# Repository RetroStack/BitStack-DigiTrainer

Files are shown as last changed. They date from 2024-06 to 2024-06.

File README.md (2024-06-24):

# DigiTrainer

As part of an introduction in digital electronics workshop at VCF SW 2024, I prepared this board. The intent was to reduce lookup time for datasheets and being able to just connect the inputs and outputs of various gates and logic ICs without caring too much about power supplies. In addition, this board features DIP-switches, a toggle and slide switch, hexadecimal switches, LED arrays which do have a built in resistor for current limiting, pull-up and -down resistors, and much more.

In addition to all of that, it includes a section for a Z80 CPU, static memory, and a ROM to be able to learn to program and work with 8-bit CPUs.

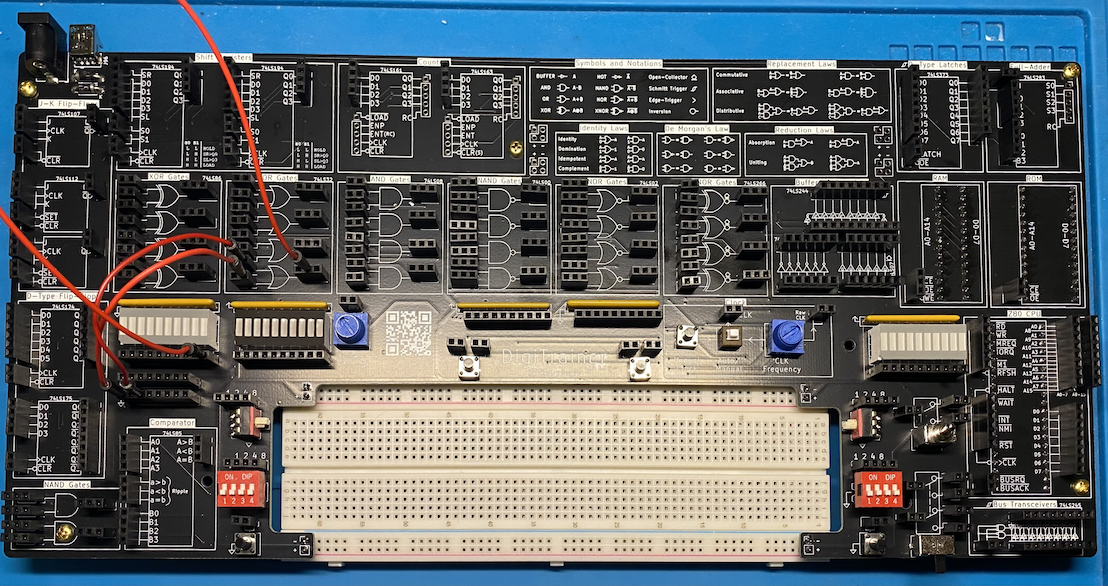
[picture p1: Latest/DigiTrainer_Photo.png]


## Latest Files

In the "Latest" folder, you'll find the most up-to-date design files, including:

- Gerber files suitable for popular online PCB manufacturers like [PCBWay](/Latest/DigiTrainer_Gerber_PCBWay.zip) and [JLCPCB](/Latest/DigiTrainer_Gerber_JLCPCB.zip). Most manufacturers should be fine with either.
- A Bill of Materials (BOM) in both [CSV](/Latest/DigiTrainer_BOM.csv) and [PDF](/Latest/DigiTrainer_BOM.pdf) formats.
- The [full schematics](/Latest/DigiTrainer_Schematics.pdf) of the board.

## Implementation

The board has been implemented using KiCAD 8. The KiCAD project files are included in this repository.

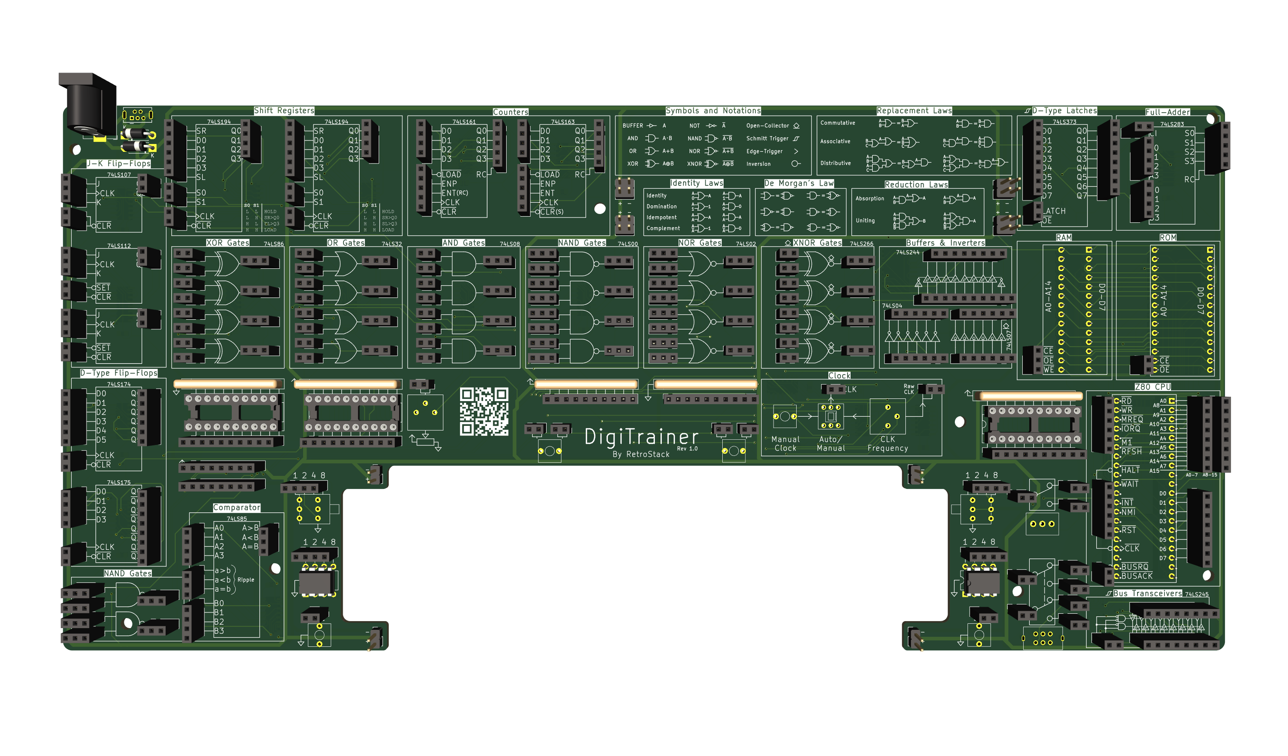
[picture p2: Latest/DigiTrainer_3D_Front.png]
Front

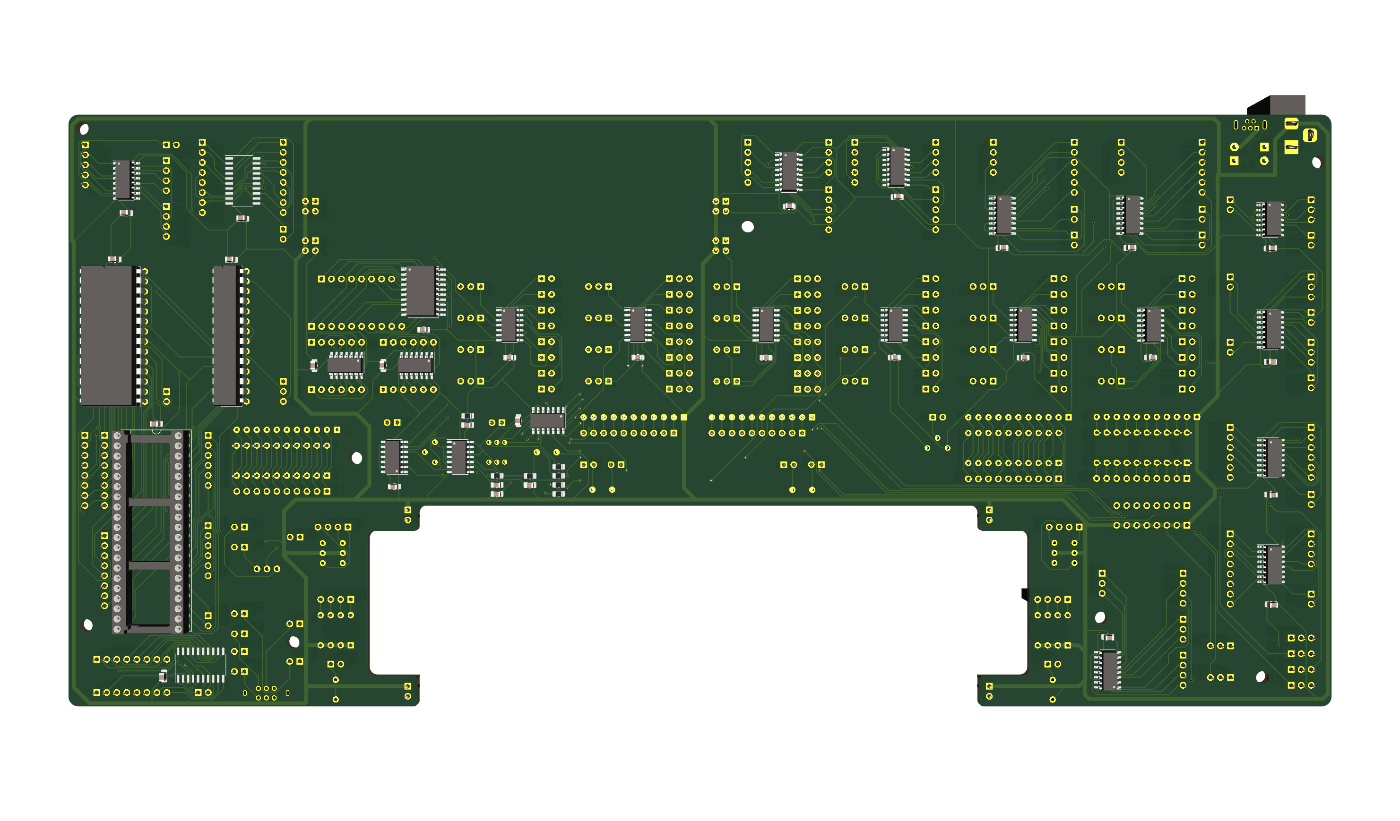
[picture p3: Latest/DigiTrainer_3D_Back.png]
Back


## How to Use

All inputs of various ICs and gates are on the left side of the indicated gate or IC, while outputs are on the right side of the silkscreen indications. Bi-directional pins are horizontal or on the output side (such as at the Z80 CPU for the data bus).

Many components are already connected to +5V or GND and are indicated by an "arrow up" and "triangle down" respectively. Keep in mind that an LED connected to an IC output with +5V acts as an inverted output due to current sinking.

The top right area also provides a legend of common rules/laws and symbols used in digital electronics (and logic as an extension of it).

## Bill of Materials (BOM)

Below is a list of materials needed to assemble the PCB.

| Reference | Qty | Description | Footprint | Datasheet |
| --- | --- | --- | --- | --- |
| C1,C2,C3,C4,C5,C6,C7,C8,C9,C10,C11,C12,C13,C14,C15,C16,C17,C18,C19,C20,C25,C26,C27,C28,C29,C30 | 26  | 0.1uF | Capacitor_SMD:C_0805_2012Metric_Pad1.18x1.45mm_HandSolder  | ~ |
| C21,C24 | 2 | 1uF | Capacitor_SMD:C_0805_2012Metric_Pad1.18x1.45mm_HandSolder  | ~ |
| C22,C23 | 2 | 0.01uF | Capacitor_SMD:C_0805_2012Metric_Pad1.18x1.45mm_HandSolder  | ~ |
| D1,D2 | 2 | D_Schottky | Diode_THT:D_DO-41_SOD81_P7.62mm_Horizontal | ~ |
| DN1,DN2,DN3 | 3 | LED Array | Package_DIP:DIP-20_W7.62mm_Socket | ~ |
| J1,J2,J86,J158,J159,J160 | 6 | Conn_01x10 | Connector_PinSocket_2.54mm:PinSocket_1x10_P2.54mm_Vertical | ~ |
| J3,J16,J17,J18,J19,J20,J21,J22,J23,J24,J25,J26,J27,J28,J29,J30,J31,J54,J55,J56,J57,J58,J59,J60,J61,J62,J63,J64,J65,J66,J67,J68,J69,J89,J99,J100,J102,J109,J110,J111,J112,J113,J114,J122,J123,J125,J126,J133,J137,J138,J142,J144,J145,J146,J147,J148,J149,J150,J151,J152,J153,J154,J155,J156,J157,J163,J168 | 67  | Conn_01x02 | Connector_PinSocket_2.54mm:PinSocket_1x02_P2.54mm_Vertical | ~ |
| J4,J5,J6,J7,J8,J9,J10,J11,J12,J13,J14,J15,J32,J33,J34,J35,J36,J37,J38,J39,J40,J41,J42,J43,J44,J45,J46,J47,J48,J49,J50,J51,J52,J53,J70,J71,J72,J73,J74,J75,J76,J77,J78,J79,J80,J81,J87,J106,J107,J108,J135,J136,J141,J143,J167,J169 | 56  | Conn_01x03 | Connector_PinSocket_2.54mm:PinSocket_1x03_P2.54mm_Vertical | ~ |
| J82,J83,J84,J85,J98,J103,J121,J124,J161,J162 | 10  | Conn_01x06 | Connector_PinSocket_2.54mm:PinSocket_1x06_P2.54mm_Vertical | ~ |
| J88,J90,J91,J101,J104,J105,J164,J165,J166,J173,J174 | 11  | Conn_01x08 | Connector_PinSocket_2.54mm:PinSocket_1x08_P2.54mm_Vertical | ~ |
| J92,J93,J94,J172 | 4 | Conn_02x02_Odd_Even | Connector_PinHeader_2.54mm:PinHeader_2x02_P2.54mm_Vertical | ~ |
| J95 | 1 | Barrel_Jack_Switch  | Connector_BarrelJack:BarrelJack_Horizontal | ~ |
| J96 | 1 | USB_B_Mini | Connector_USB:USB_Mini-B_Tensility_54-00023_Vertical | ~ |
| J97,J115,J117,J127,J128,J129,J130,J131,J132,J139,J140,J170,J171 | 13  | Conn_01x04 | Connector_PinSocket_2.54mm:PinSocket_1x04_P2.54mm_Vertical | ~ |
| J116,J118,J119,J120,J134 | 5 | Conn_01x05 | Connector_PinSocket_2.54mm:PinSocket_1x05_P2.54mm_Vertical | ~ |
| R1,R2,R3 | 3 | 10k | Resistor_SMD:R_0805_2012Metric_Pad1.20x1.40mm_HandSolder | ~ |
| R4,R5,R6,R7 | 4 | 1k | Resistor_SMD:R_0805_2012Metric_Pad1.20x1.40mm_HandSolder | ~ |
| RN1,RN2,RN3,RN4,RN5 | 5 | R_Network10 | Resistor_THT:R_Array_SIP11 | http://www.vishay.com/docs/31509/csc.pdf |
| RV1 | 1 | R_Potentiometer | Potentiometer_THT:Potentiometer_Bourns_3386P_Vertical | ~ |
| RV2 | 1 | 1M | Potentiometer_THT:Potentiometer_Bourns_3386P_Vertical | ~ |
| SW1,SW5,SW6,SW7,SW8 | 5 | SW_Push | RetroStackLibrary:SW_SPST_Push | ~ |
| SW2 | 1 | SW_DPDT_x2 | RetroStackLibrary:SW_DPDT_Push | ~ |
| SW3,SW4 | 2 | SW_DIP_x04 | Package_DIP:DIP-8_W7.62mm | ~ |
| SW9 | 1 | SW_SPDT | RetroStackLibrary:SW_SPDT_Toggle | ~ |
| SW10 | 1 | SW_Push_DPDT | RetroStackLibrary:SW_DPDT_Slide_RightAngle | ~ |
| SW11,SW12 | 2 | Hex Switch | RetroStackLibrary:SW_Hexadecimal_Horizontal | https://www.ckswitches.com/media/1333/cd.pdf |
| U1 | 1 | 74LS07 | Package_SO:SOIC-14_3.9x8.7mm_P1.27mm | www.ti.com/lit/ds/symlink/sn74ls07.pdf |
| U2 | 1 | 74LS04 | Package_SO:SOIC-14_3.9x8.7mm_P1.27mm | http://www.ti.com/lit/gpn/sn74LS04 |
| U3 | 1 | 74LS266 | Package_SO:SOIC-14_3.9x8.7mm_P1.27mm | ~ |
| U4,U5 | 2 | 74LS00 | Package_SO:SOIC-14_3.9x8.7mm_P1.27mm | http://www.ti.com/lit/gpn/sn74ls00 |
| U6 | 1 | 74LS08 | Package_SO:SOIC-14_3.9x8.7mm_P1.27mm | http://www.ti.com/lit/gpn/sn74LS08 |
| U7 | 1 | 74LS86 | Package_SO:SOIC-14_3.9x8.7mm_P1.27mm | 74xx/74ls86.pdf |
| U8 | 1 | 74LS32 | Package_SO:SOIC-14_3.9x8.7mm_P1.27mm | http://www.ti.com/lit/gpn/sn74LS32 |
| U9 | 1 | 74LS02 | Package_SO:SOIC-14_3.9x8.7mm_P1.27mm | http://www.ti.com/lit/gpn/sn74ls02 |
| U10 | 1 | 74LS244 | Package_SO:SOIC-20W_7.5x12.8mm_P1.27mm | http://www.ti.com/lit/ds/symlink/sn74ls244.pdf |
| U11 | 1 | 74LS245 | Package_SO:SO-20_5.3x12.6mm_P1.27mm | http://www.ti.com/lit/gpn/sn74LS245 |
| U12 | 1 | 74LS51 | Package_SO:SOIC-14_3.9x8.7mm_P1.27mm | http://www.ti.com/lit/ds/symlink/sn74ls51.pdf |
| U13 | 1 | 74LS174 | Package_SO:SOIC-16_3.9x9.9mm_P1.27mm | http://www.ti.com/lit/gpn/sn74LS174 |
| U14 | 1 | 74LS175 | Package_SO:SOIC-16_3.9x9.9mm_P1.27mm | http://www.ti.com/lit/gpn/sn74LS175 |
| U15 | 1 | 74LS373 | Package_SO:SO-20_5.3x12.6mm_P1.27mm | http://www.ti.com/lit/gpn/sn74LS373 |
| U16 | 1 | 74LS112 | Package_SO:SOIC-16_3.9x9.9mm_P1.27mm | http://www.ti.com/lit/gpn/sn74LS112 |
| U17 | 1 | 74LS107 | Package_SO:SOIC-14_3.9x8.7mm_P1.27mm | http://www.ti.com/lit/gpn/sn74LS107 |
| U18 | 1 | 74LS161 | Package_SO:SOIC-16_3.9x9.9mm_P1.27mm | http://www.ti.com/lit/gpn/sn74LS161 |
| U19 | 1 | 74LS163 | Package_SO:SOIC-16_3.9x9.9mm_P1.27mm | http://www.ti.com/lit/gpn/sn74LS163 |
| U20,U21 | 2 | 74LS194 | Package_SO:SOIC-16_3.9x9.9mm_P1.27mm | http://www.ti.com/lit/gpn/sn74LS194 |
| U22 | 1 | 74LS283 | Package_SO:SOIC-16_3.9x9.9mm_P1.27mm | http://www.ti.com/lit/gpn/sn74LS283 |
| U23 | 1 | 74LS85 | Package_SO:SOIC-16_3.9x9.9mm_P1.27mm | http://www.ti.com/lit/gpn/sn74LS85 |
| U24 | 1 | NE556 | Package_SO:SOIC-14_3.9x8.7mm_P1.27mm | http://www.ti.com/lit/ds/symlink/ne556.pdf |
| U25 | 1 | Z80CPU | Package_DIP:DIP-40_W15.24mm_Socket | www.zilog.com/manage_directlink.php?filepath=docs/z80/um0080 |
| U26 | 1 | ROM_27256 | Package_DIP:DIP-28_W15.24mm | ~ |
| U27 | 1 | CY7C199 | Package_DIP:DIP-28_W7.62mm | ~ |

## RetroStack Libraries

To work with this KiCAD project, you'll need the RetroStack libraries for KiCAD. Please [follow this link](https://www.github.com/RetroStack/KiCAD-Libraries) to access and install these libraries.

## Support this Project

RetroStack is passionate about exploring and preserving the legacy of older computer systems. BitStack is a sub-project of RetroStack, focusing on education in digital electronics. My work involves creating detailed documentation and videos to share the knowledge. I am also dedicated to reviving these classic systems by reimplementing them and offering replacement parts at no cost. If you're keen on supporting this unique project, I invite you to visit my [Patreon page](https://www.patreon.com/RetroStack). Your support would be immensely valuable and greatly appreciated!

## License

This project is licensed under the MIT License - see the [LICENSE](LICENSE) file for details.

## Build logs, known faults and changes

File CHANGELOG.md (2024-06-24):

# DigiTrainer - Changelog

## 24th June 2024 - Rev 1.0

Completed test. Fully functional.

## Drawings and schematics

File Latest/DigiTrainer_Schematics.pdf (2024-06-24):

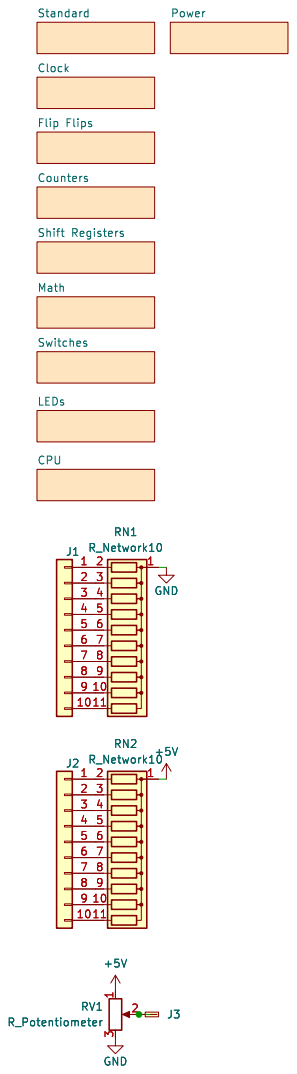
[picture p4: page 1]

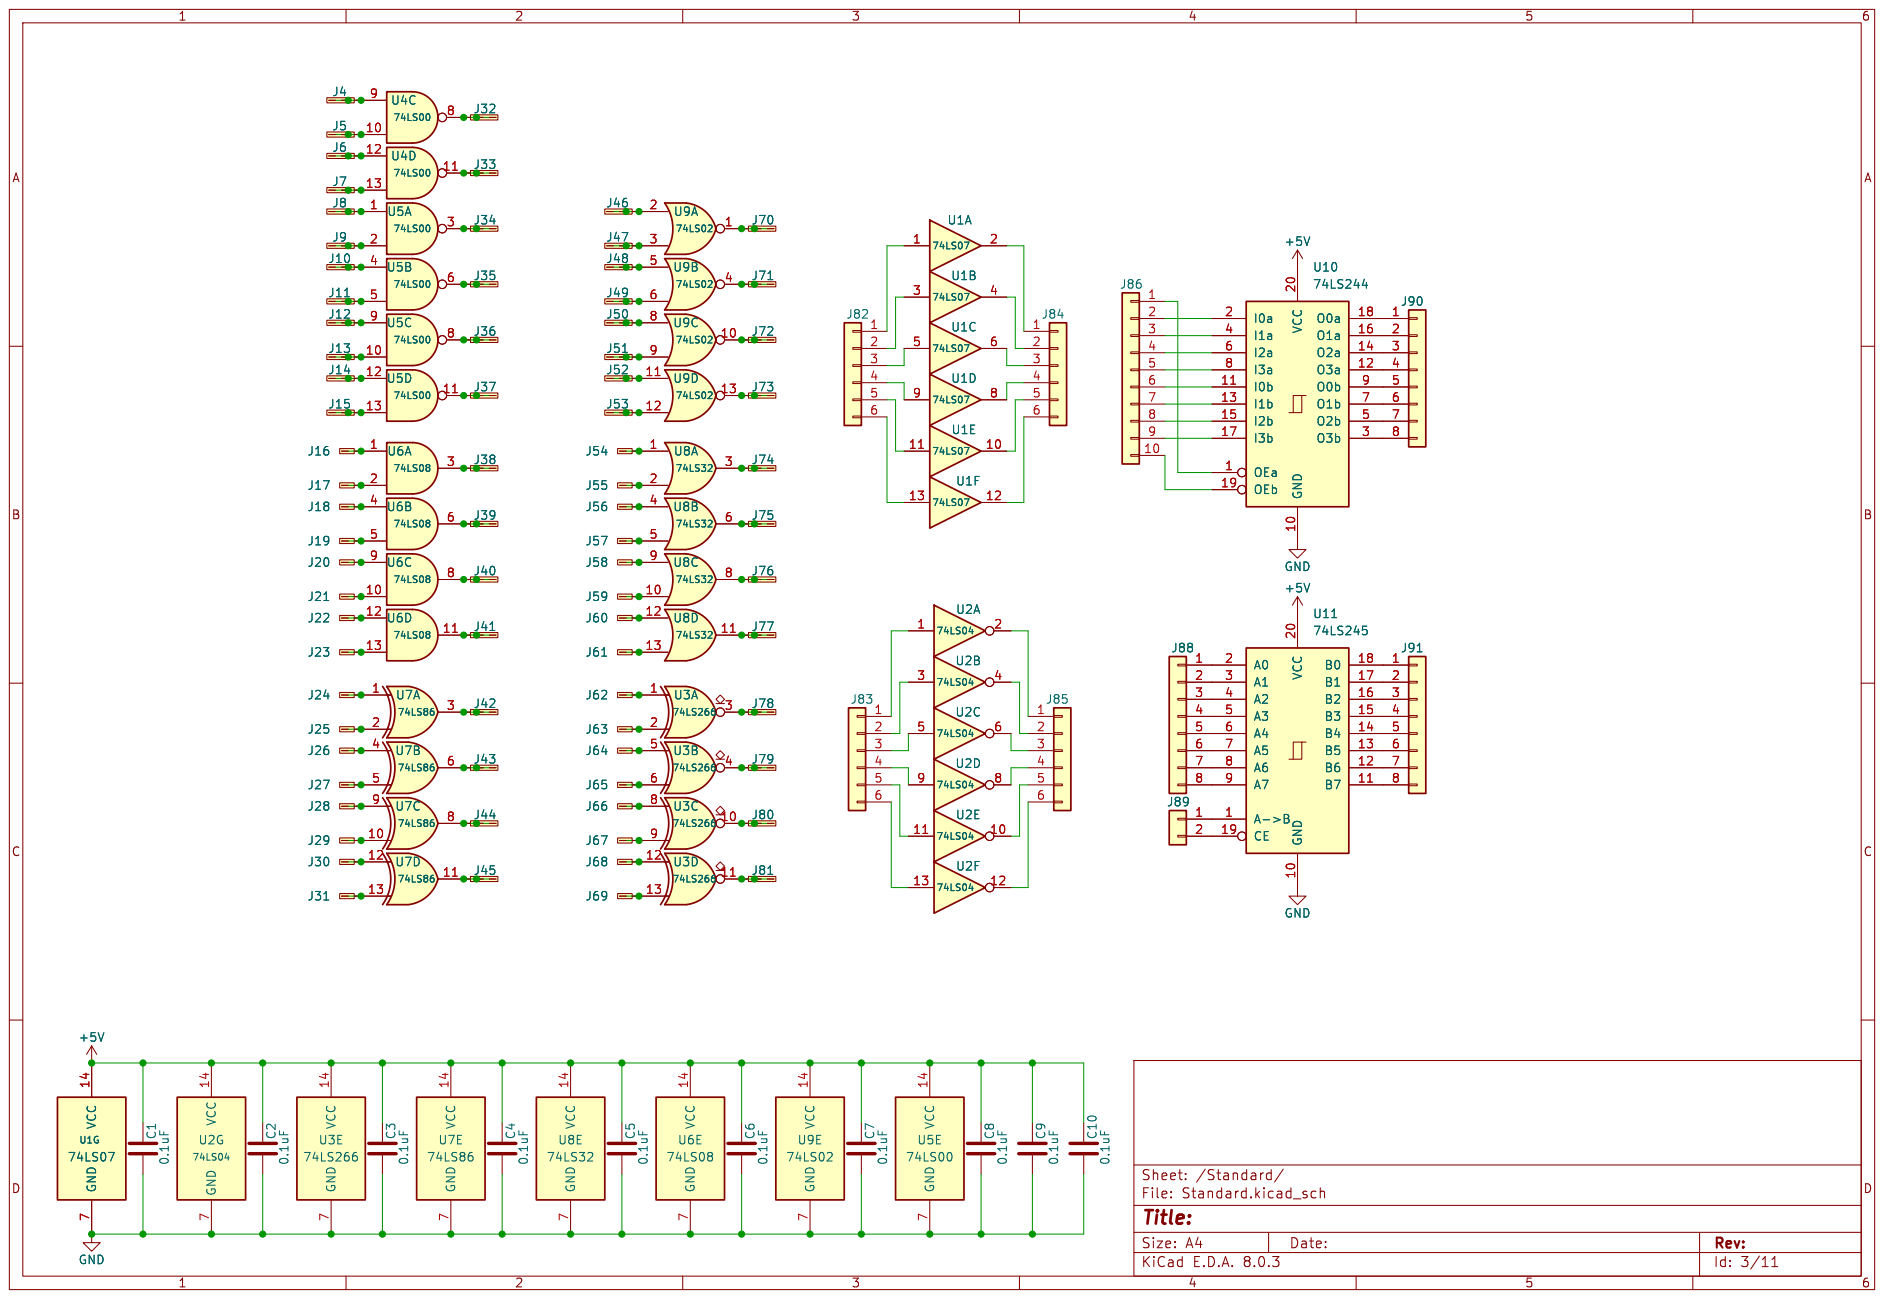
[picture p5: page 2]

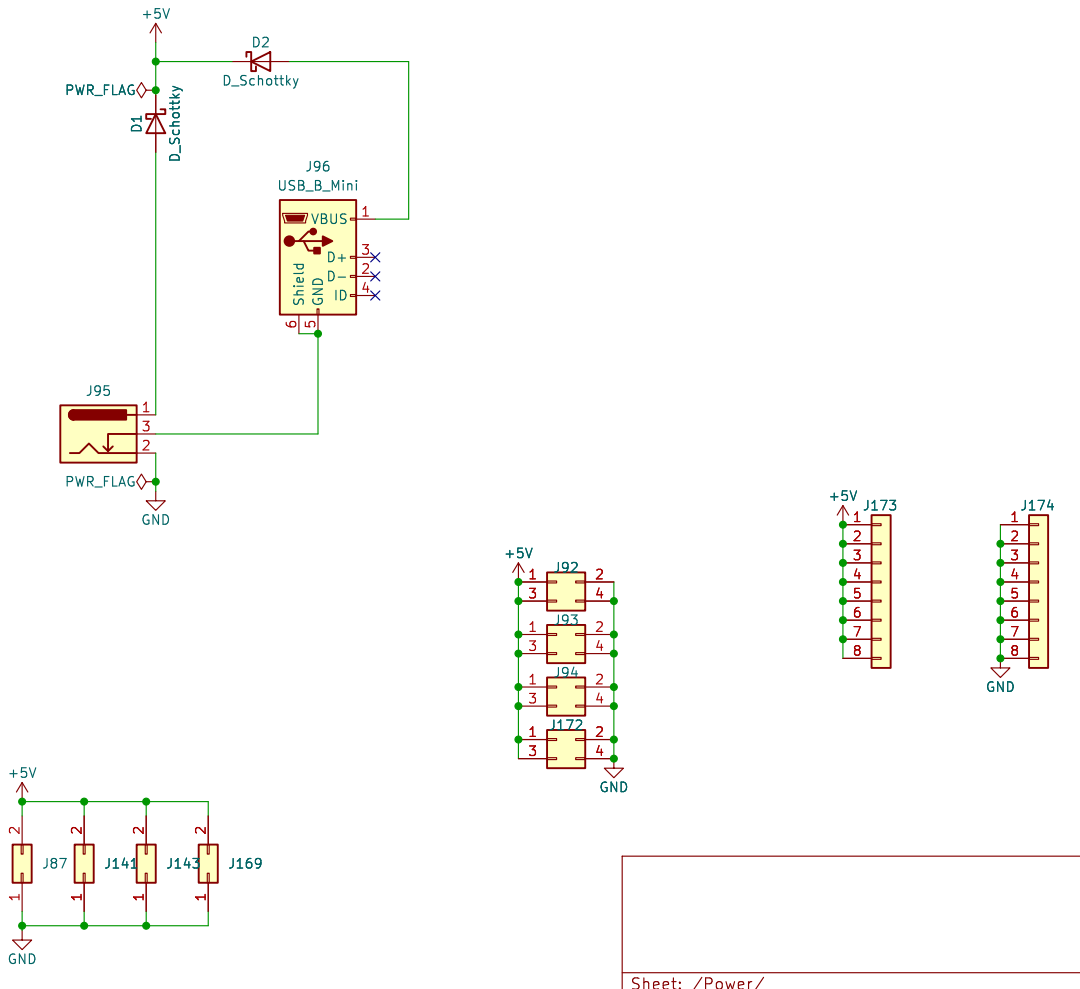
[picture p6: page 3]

Id: 4/11 Title: File: Power.kicad_sch Sheet: /Power/ 1 2

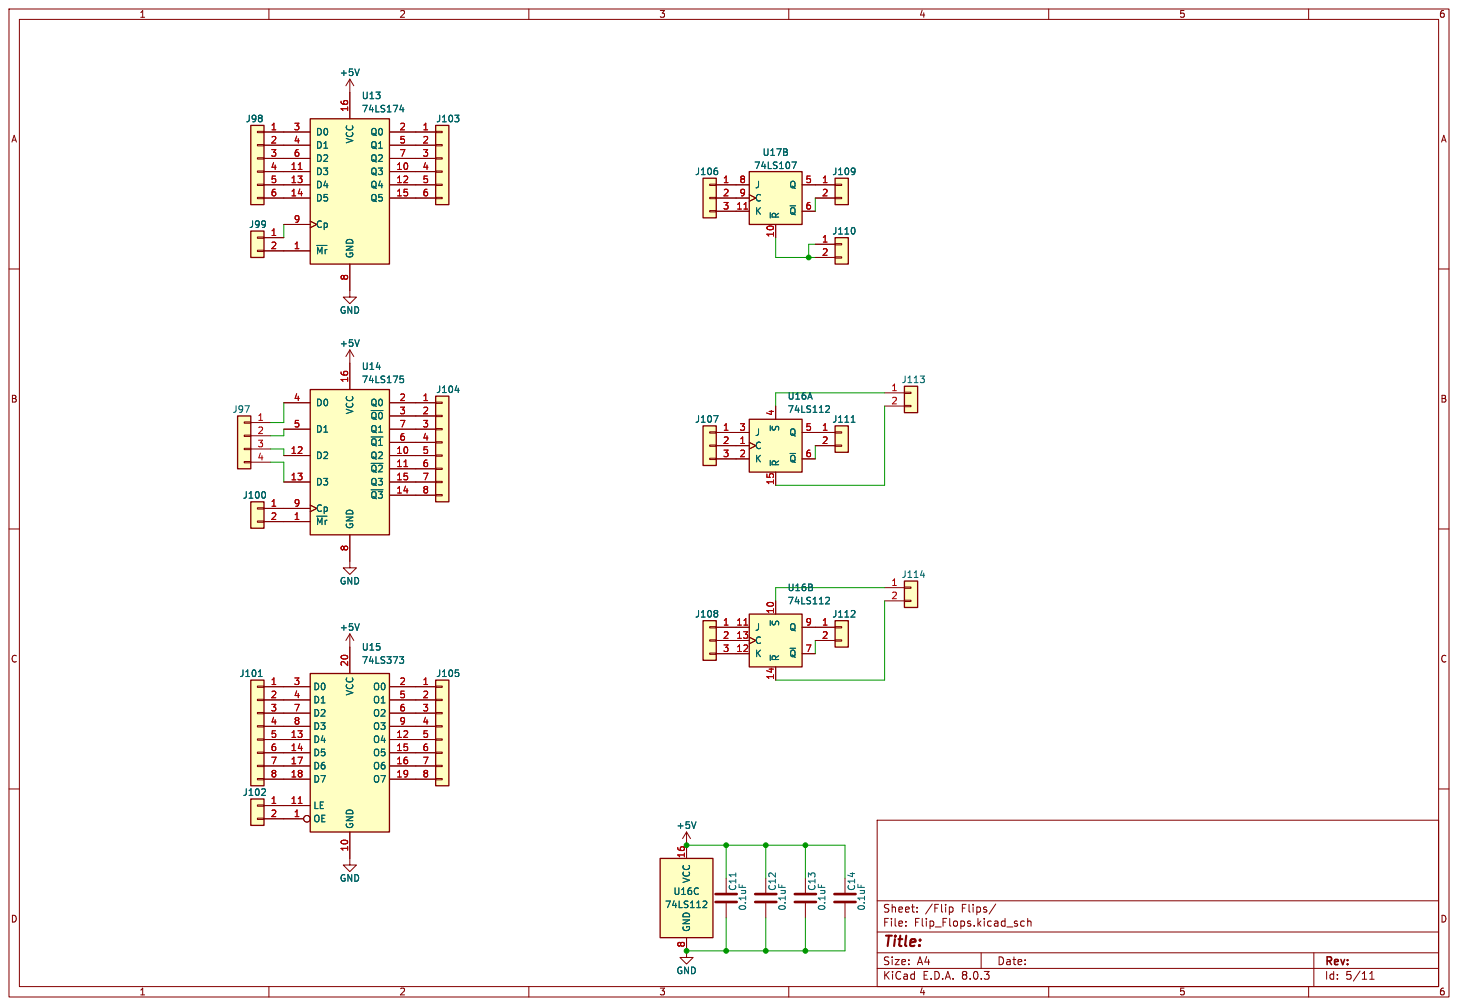
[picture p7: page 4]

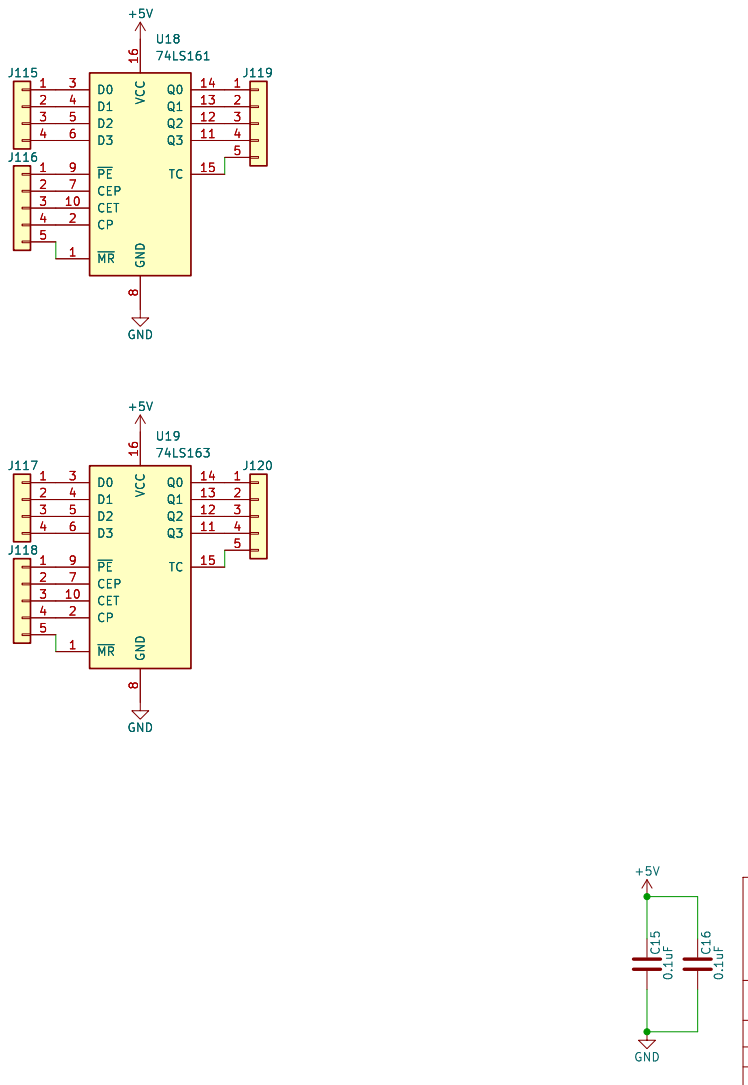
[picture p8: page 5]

Id: 5/11 Title: File: Counters.kicad_sch Sheet: /Counters/ GND

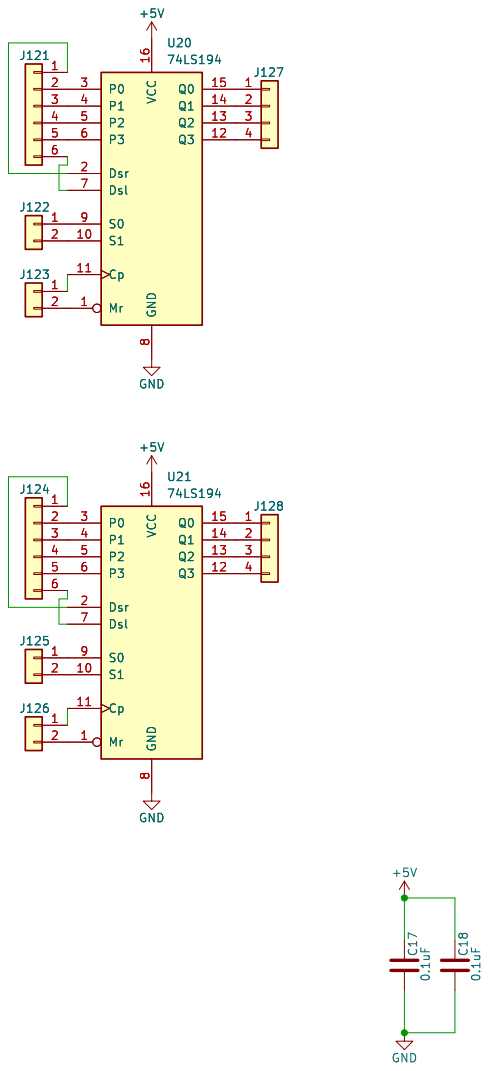
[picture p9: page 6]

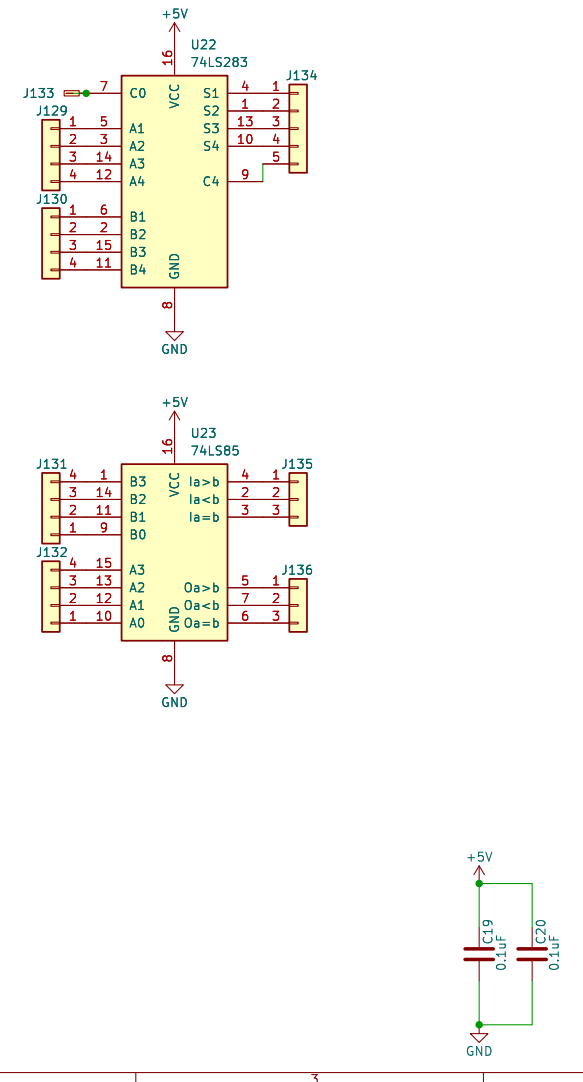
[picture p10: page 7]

Id: 7/11 Title: File: Math.kicad_sch Sheet: /Math/ GND GND 1234

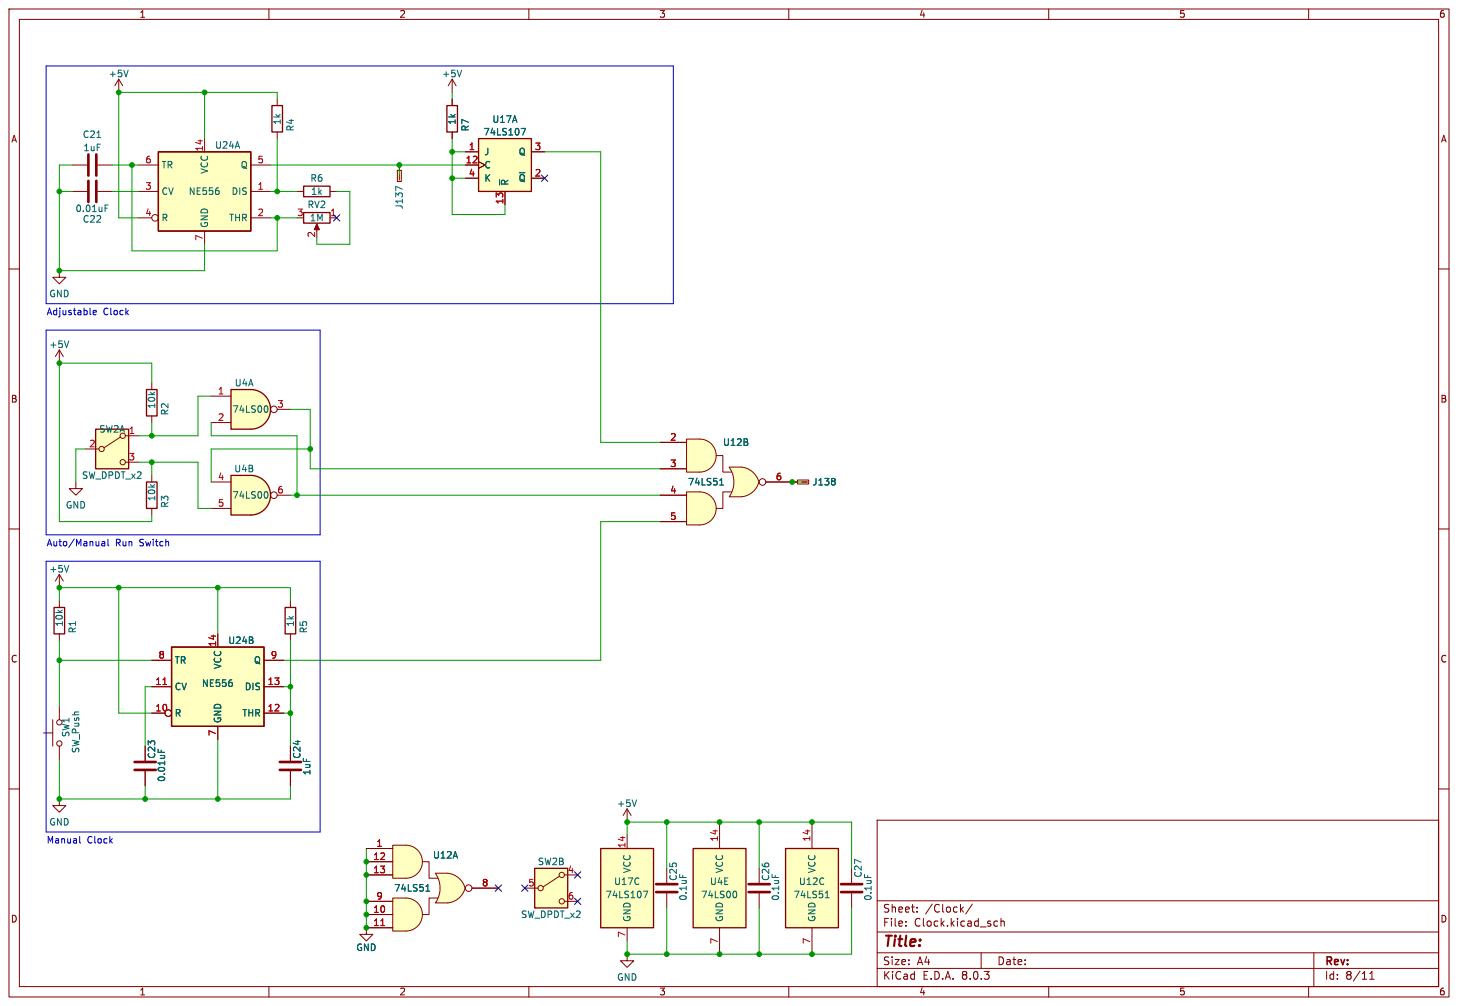
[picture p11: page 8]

Id: 8/11 Title: File: Clock.kicad_sch Sheet: /Clock/ VCC 14 GND 7 U12C

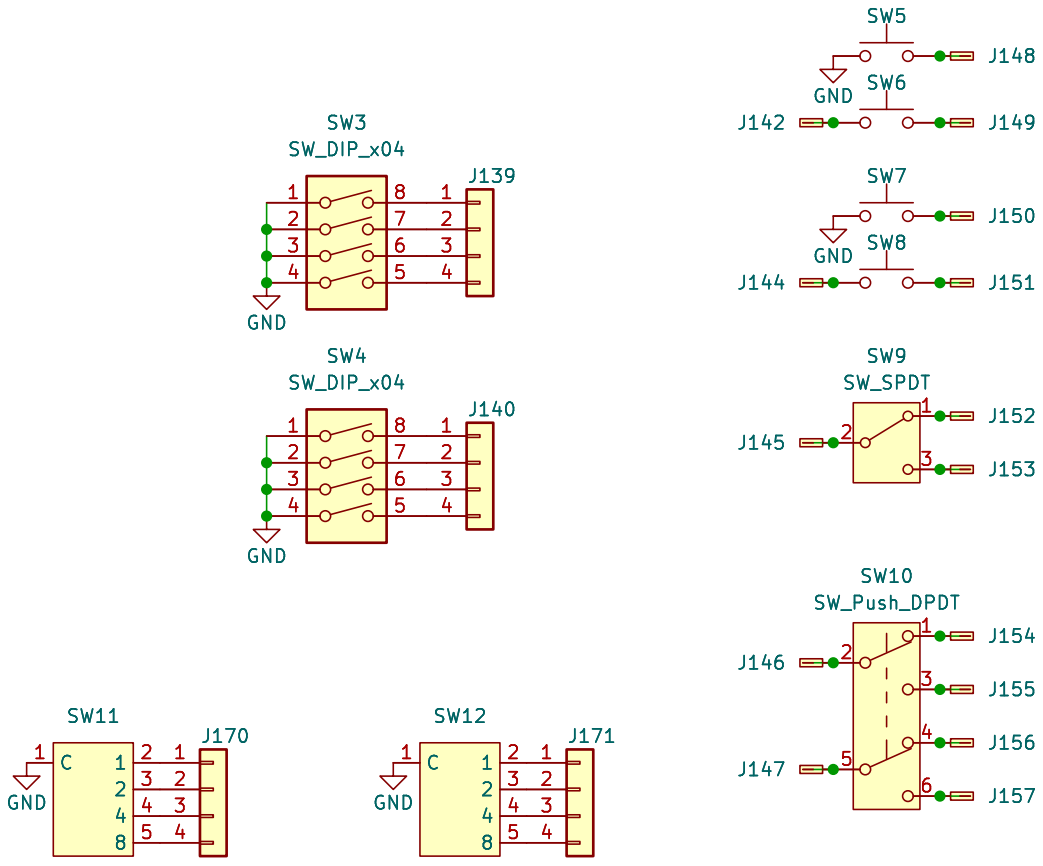
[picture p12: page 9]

Id: 9/11 Title: File: Switches.kicad_sch Sheet: /Switches/

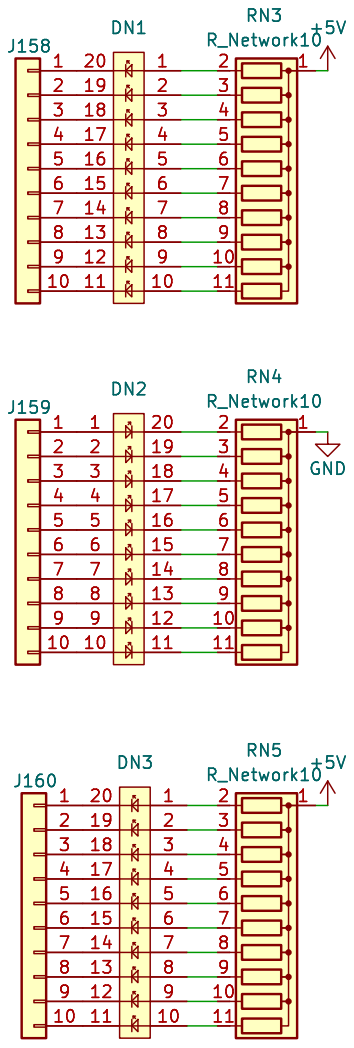
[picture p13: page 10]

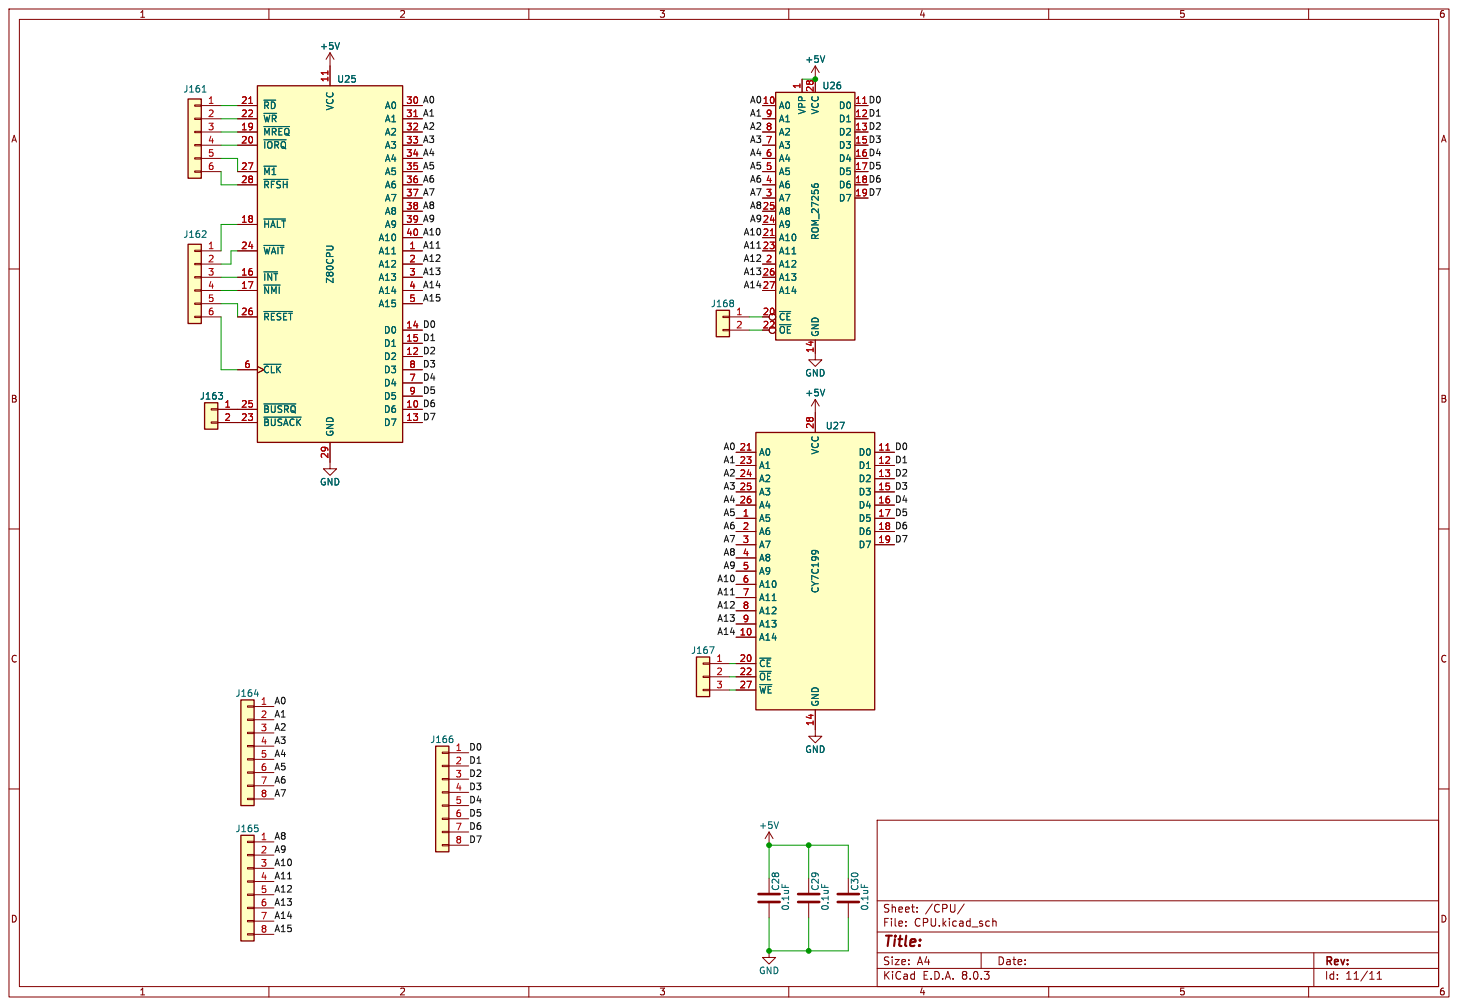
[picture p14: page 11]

Id: 11/11 Title: File: CPU.kicad_sch Sheet: /CPU/ 12345678

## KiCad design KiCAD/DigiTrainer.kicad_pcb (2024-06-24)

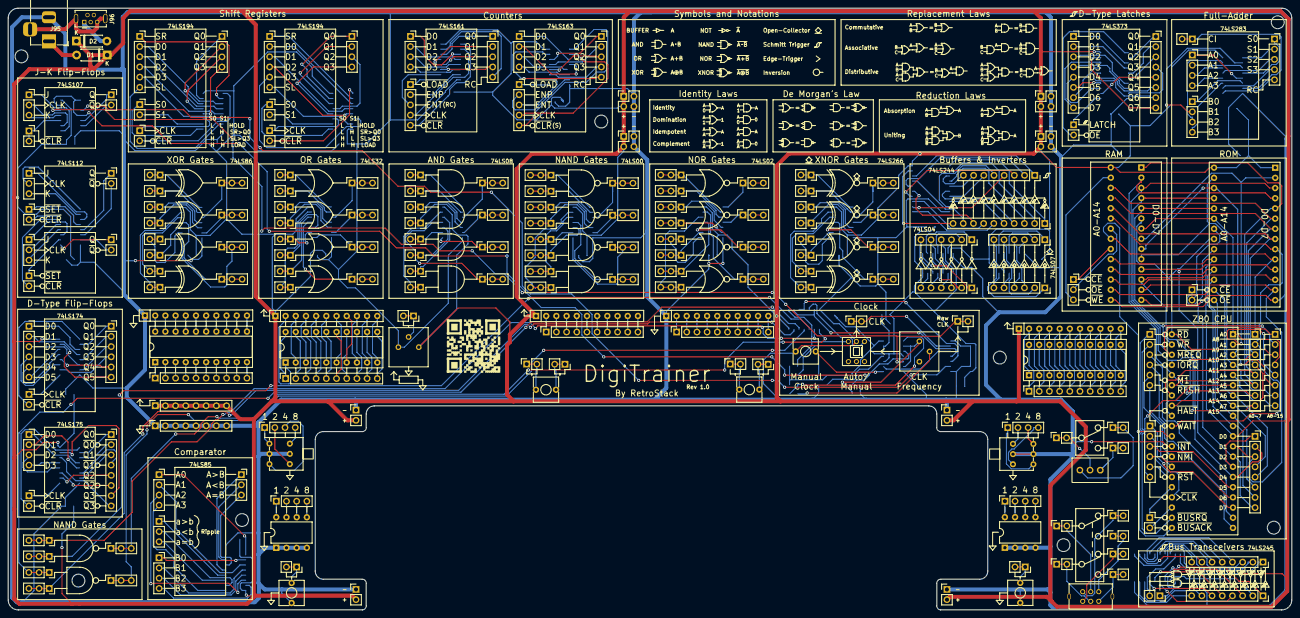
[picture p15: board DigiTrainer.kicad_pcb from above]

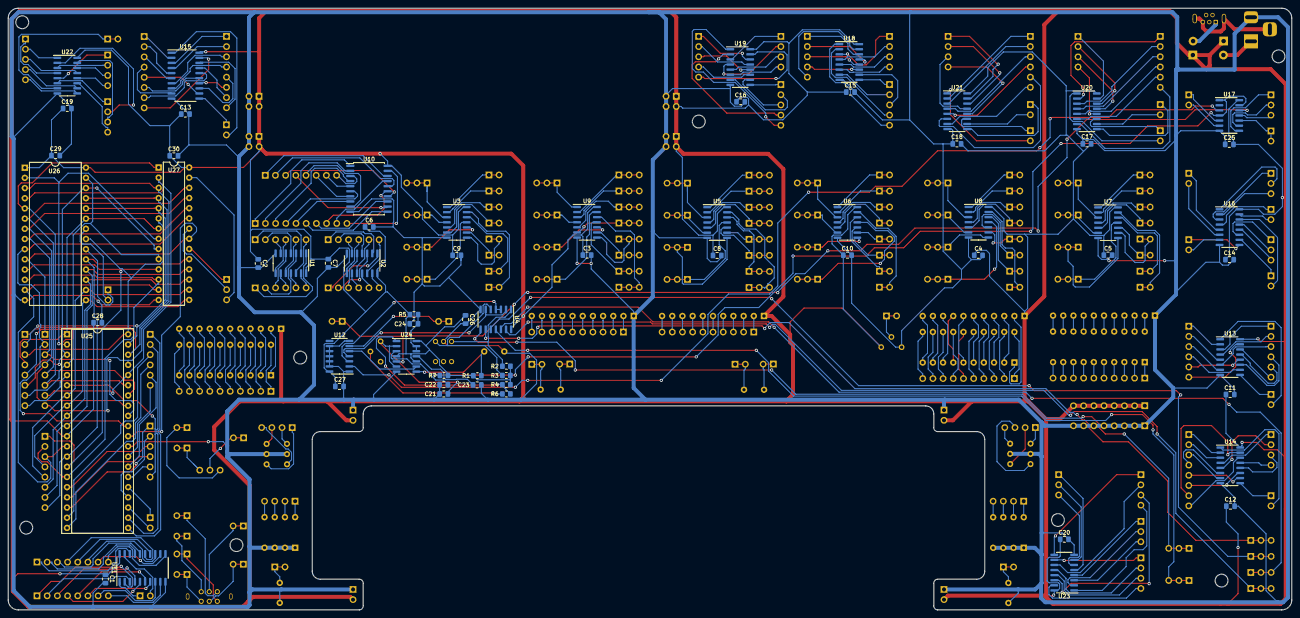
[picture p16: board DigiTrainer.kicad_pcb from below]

Board: 2 copper layers, 320.0 x 150.0 mm, 262 parts (64 on the bottom side), 464 nets.

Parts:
C1, C2, C3, C4, C5, C6, C7, C8, C9, C10, C11, C12, C13, C14, C15, C16, C17, C18, C19, C20, C25, C26, C27, C28, C29, C30: 0.1uF; C_0805_2012Metric_Pad1.18x1.45mm_HandSolder
C21, C24: 1uF; C_0805_2012Metric_Pad1.18x1.45mm_HandSolder
C22, C23: 0.01uF; C_0805_2012Metric_Pad1.18x1.45mm_HandSolder
D1, D2: D_Schottky; D_DO-41_SOD81_P7.62mm_Horizontal
DN1, DN2, DN3: DIP-20_W7.62mm_Socket
J1, J2, J86, J158, J159, J160: Conn_01x10; PinSocket_1x10_P2.54mm_Vertical
J3, J16, J17, J18, J19, J20, J21, J22, J23, J24, J25, J26, J27, J28, J29, J30, J31, J54, J55, J56, J57, J58, J59, J60, J61, J62, J63, J64, J65, J66, J67, J68, J69, J133, J137, J138, J142, J144, J145, J146, J147, J148, J149, J150, J151, J152, J153, J154, J155, J156, J157: PinSocket_1x02_P2.54mm_Vertical
J4, J5, J6, J7, J8, J9, J10, J11, J12, J13, J14, J15, J32, J33, J34, J35, J36, J37, J38, J39, J40, J41, J42, J43, J44, J45, J46, J47, J48, J49, J50, J51, J52, J53, J70, J71, J72, J73, J74, J75, J76, J77, J78, J79, J80, J81: PinSocket_1x03_P2.54mm_Vertical
J82, J83, J84, J85, J98, J103, J121, J124, J161, J162: Conn_01x06; PinSocket_1x06_P2.54mm_Vertical
J87, J141, J143, J169: Conn_02x01; PinHeader_1x02_P2.54mm_Vertical
J88, J90, J91, J101, J104, J105, J164, J165, J166, J173, J174: Conn_01x08; PinSocket_1x08_P2.54mm_Vertical
J89, J99, J100, J102, J109, J110, J111, J112, J113, J114, J122, J123, J125, J126, J163, J168: Conn_01x02; PinSocket_1x02_P2.54mm_Vertical
J92, J93, J94, J172: Conn_02x02_Odd_Even; PinHeader_2x02_P2.54mm_Vertical
J95: Barrel_Jack_Switch; BarrelJack_Horizontal
J96: USB_B_Mini; USB_Mini-B_Tensility_54-00023_Vertical
J97, J115, J117, J127, J128, J129, J130, J131, J132, J139, J140, J170, J171: Conn_01x04; PinSocket_1x04_P2.54mm_Vertical
J106, J107, J108, J135, J136, J167: Conn_01x03; PinSocket_1x03_P2.54mm_Vertical
J116, J118, J119, J120, J134: Conn_01x05; PinSocket_1x05_P2.54mm_Vertical
R1, R2, R3: 10k; R_0805_2012Metric_Pad1.20x1.40mm_HandSolder
R4, R5, R6, R7: 1k; R_0805_2012Metric_Pad1.20x1.40mm_HandSolder
RN1, RN2, RN3, RN4, RN5: R_Network10; R_Array_SIP11
RV1: R_Potentiometer; Potentiometer_Bourns_3386P_Vertical
RV2: 1M; Potentiometer_Bourns_3386P_Vertical
SW1, SW5, SW6, SW7, SW8: SW_Push; SW_SPST_Push
SW2: SW_DPDT_x2; SW_DPDT_Push
SW3, SW4: SW_DIP_x04; DIP-8_W7.62mm
SW9: SW_SPDT; SW_SPDT_Toggle
SW10: SW_Push_DPDT; SW_DPDT_Slide_RightAngle
SW11, SW12: SW_Hexadecimal_Horizontal
U1: 74LS07; SOIC-14_3.9x8.7mm_P1.27mm
U2: 74LS04; SOIC-14_3.9x8.7mm_P1.27mm
U3: 74LS266; SOIC-14_3.9x8.7mm_P1.27mm
U4, U5: 74LS00; SOIC-14_3.9x8.7mm_P1.27mm
U6: 74LS08; SOIC-14_3.9x8.7mm_P1.27mm
U7: 74LS86; SOIC-14_3.9x8.7mm_P1.27mm
U8: 74LS32; SOIC-14_3.9x8.7mm_P1.27mm
U9: 74LS02; SOIC-14_3.9x8.7mm_P1.27mm
U10: 74LS244; SOIC-20W_7.5x12.8mm_P1.27mm
U11: 74LS245; SO-20_5.3x12.6mm_P1.27mm
U12: 74LS51; SOIC-14_3.9x8.7mm_P1.27mm
U13: 74LS174; SOIC-16_3.9x9.9mm_P1.27mm
U14: 74LS175; SOIC-16_3.9x9.9mm_P1.27mm
U15: 74LS373; SO-20_5.3x12.6mm_P1.27mm
U16: 74LS112; SOIC-16_3.9x9.9mm_P1.27mm
U17: 74LS107; SOIC-14_3.9x8.7mm_P1.27mm
U18: 74LS161; SOIC-16_3.9x9.9mm_P1.27mm
U19: 74LS163; SOIC-16_3.9x9.9mm_P1.27mm
U20, U21: 74LS194; SOIC-16_3.9x9.9mm_P1.27mm
U22: 74LS283; SOIC-16_3.9x9.9mm_P1.27mm
U23: 74LS85; SOIC-16_3.9x9.9mm_P1.27mm
U24: NE556; SOIC-14_3.9x8.7mm_P1.27mm
U25: Z80CPU; DIP-40_W15.24mm_Socket
U26: ROM_27256; DIP-28_W15.24mm
U27: CY7C199; DIP-28_W7.62mm

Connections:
+5V: C1.1, C2.1, C3.1, C4.1, C5.1, C6.1, C7.1, C8.1, C9.1, C10.1, C11.1, C12.1, C13.1, C14.1, C15.1, C16.1, C17.1, C18.1, C19.1, C20.1, C25.1, C26.1, C27.1, C28.1, C29.1, C30.1, D1.1 (K), D2.1 (K), J87.2, J92.1, J92.3, J93.1, J93.3, J94.1, J94.3, J141.2, J143.2, J169.2, J172.1, J172.3, J173.1, J173.2, J173.3, J173.4, J173.5, J173.6, J173.7, J173.8, R1.2, R2.1, R3.2, R4.1, R5.1, R7.1, RN2.1 (common), RN3.1 (common), RN5.1 (common), RV1.1, U1.14 (VCC), U2.14 (VCC), U3.14 (VCC), U4.14 (VCC), U5.14 (VCC), U6.14 (VCC), U7.14 (VCC), U8.14 (VCC), U9.14 (VCC), U10.20 (VCC), U11.20 (VCC), U12.14 (VCC), U13.16 (VCC), U14.16 (VCC), U15.20 (VCC), U16.16 (VCC), U17.14 (VCC), U18.16 (VCC), U19.16 (VCC), U20.16 (VCC), U21.16 (VCC), U22.16 (VCC), U23.16 (VCC), U24.4 (R), U24.10 (R), U24.14 (VCC), U25.11 (VCC), U26.1 (VPP), U26.28 (VCC), U27.28 (VCC)
/CPU/A0: J164.1, U25.30 (A0), U26.10 (A0), U27.21 (A0)
/CPU/A1: J164.2, U25.31 (A1), U26.9 (A1), U27.23 (A1)
/CPU/A2: J164.3, U25.32 (A2), U26.8 (A2), U27.24 (A2)
/CPU/A3: J164.4, U25.33 (A3), U26.7 (A3), U27.25 (A3)
/CPU/A4: J164.5, U25.34 (A4), U26.6 (A4), U27.26 (A4)
/CPU/A5: J164.6, U25.35 (A5), U26.5 (A5), U27.1 (A5)
/CPU/A6: J164.7, U25.36 (A6), U26.4 (A6), U27.2 (A6)
/CPU/A7: J164.8, U25.37 (A7), U26.3 (A7), U27.3 (A7)
/CPU/A8: J165.1, U25.38 (A8), U26.25 (A8), U27.4 (A8)
/CPU/A9: J165.2, U25.39 (A9), U26.24 (A9), U27.5 (A9)
/CPU/A10: J165.3, U25.40 (A10), U26.21 (A10), U27.6 (A10)
/CPU/A11: J165.4, U25.1 (A11), U26.23 (A11), U27.7 (A11)
/CPU/A12: J165.5, U25.2 (A12), U26.2 (A12), U27.8 (A12)
/CPU/A13: J165.6, U25.3 (A13), U26.26 (A13), U27.9 (A13)
/CPU/A14: J165.7, U25.4 (A14), U26.27 (A14), U27.10 (A14)
/CPU/A15: J165.8, U25.5 (A15)
/CPU/D0: J166.1, U25.14 (D0), U26.11 (D0), U27.11 (D0)
/CPU/D1: J166.2, U25.15 (D1), U26.12 (D1), U27.12 (D1)
/CPU/D2: J166.3, U25.12 (D2), U26.13 (D2), U27.13 (D2)
/CPU/D3: J166.4, U25.8 (D3), U26.15 (D3), U27.15 (D3)
/CPU/D4: J166.5, U25.7 (D4), U26.16 (D4), U27.16 (D4)
/CPU/D5: J166.6, U25.9 (D5), U26.17 (D5), U27.17 (D5)
/CPU/D6: J166.7, U25.10 (D6), U26.18 (D6), U27.18 (D6)
/CPU/D7: J166.8, U25.13 (D7), U26.19 (D7), U27.19 (D7)
GND: C1.2, C2.2, C3.2, C4.2, C5.2, C6.2, C7.2, C8.2, C9.2, C10.2, C11.2, C12.2, C13.2, C14.2, C15.2, C16.2, C17.2, C18.2, C19.2, C20.2, C21.1, C22.1, C23.1, C24.2, C25.2, C26.2, C27.2, C28.2, C29.2, C30.2, J87.1, J92.2, J92.4, J93.2, J93.4, J94.2, J94.4, J95.2, J141.1, J143.1, J169.1, J172.2, J172.4, J174.1, J174.2, J174.3, J174.4, J174.5, J174.6, J174.7, J174.8, RN1.1 (common), RN4.1 (common), RV1.3, SW1.1, SW2.2 (B), SW3.1, SW3.2, SW3.3, SW3.4, SW4.1, SW4.2, SW4.3, SW4.4, SW5.1, SW7.1, SW11.1 (C), SW12.1 (C), U1.7 (GND), U2.7 (GND), U3.7 (GND), U4.7 (GND), U5.7 (GND), U6.7 (GND), U7.7 (GND), U8.7 (GND), U9.7 (GND), U10.10 (GND), U11.10 (GND), U12.1, U12.7 (GND), U12.9, U12.10, U12.11, U12.12, U12.13, U13.8 (GND), U14.8 (GND), U15.10 (GND), U16.8 (GND), U17.7 (GND), U18.8 (GND), U19.8 (GND), U20.8 (GND), U21.8 (GND), U22.8 (GND), U23.8 (GND), U24.7 (GND), U25.29 (GND), U26.14 (GND), U27.14 (GND)
unnamed: D1.2 (A), J95.1
unnamed: D2.2 (A), J96.1 (VBUS)
unnamed: J1.1, RN1.2 (R1)
unnamed: J1.2, RN1.3 (R2)
unnamed: J1.3, RN1.4 (R3)
unnamed: J1.4, RN1.5 (R4)
unnamed: J1.5, RN1.6 (R5)
unnamed: J1.6, RN1.7 (R6)
unnamed: J1.7, RN1.8 (R7)
unnamed: J1.8, RN1.9 (R8)
unnamed: J1.9, RN1.10 (R9)
unnamed: J1.10, RN1.11 (R10)
unnamed: J2.1, RN2.2 (R1)
unnamed: J2.2, RN2.3 (R2)
unnamed: J2.3, RN2.4 (R3)
unnamed: J2.4, RN2.5 (R4)
unnamed: J2.5, RN2.6 (R5)
unnamed: J2.6, RN2.7 (R6)
unnamed: J2.7, RN2.8 (R7)
unnamed: J2.8, RN2.9 (R8)
unnamed: J2.9, RN2.10 (R9)
unnamed: J2.10, RN2.11 (R10)
unnamed: J3.1, J3.2, RV1.2
unnamed: J4.1, J4.2, J4.3, U4.9
unnamed: J5.1, J5.2, J5.3, U4.10
unnamed: J6.1, J6.2, J6.3, U4.12
unnamed: J7.1, J7.2, J7.3, U4.13
unnamed: J8.1, J8.2, J8.3, U5.1
unnamed: J9.1, J9.2, J9.3, U5.2
unnamed: J10.1, J10.2, J10.3, U5.4
unnamed: J11.1, J11.2, J11.3, U5.5
unnamed: J12.1, J12.2, J12.3, U5.9
unnamed: J13.1, J13.2, J13.3, U5.10
unnamed: J14.1, J14.2, J14.3, U5.12
unnamed: J15.1, J15.2, J15.3, U5.13
unnamed: J16.1, J16.2, U6.1
unnamed: J17.1, J17.2, U6.2
unnamed: J18.1, J18.2, U6.4
unnamed: J19.1, J19.2, U6.5
unnamed: J20.1, J20.2, U6.9
unnamed: J21.1, J21.2, U6.10
unnamed: J22.1, J22.2, U6.12
unnamed: J23.1, J23.2, U6.13
unnamed: J24.1, J24.2, U7.1
unnamed: J25.1, J25.2, U7.2
unnamed: J26.1, J26.2, U7.4
unnamed: J27.1, J27.2, U7.5
unnamed: J28.1, J28.2, U7.9
unnamed: J29.1, J29.2, U7.10
unnamed: J30.1, J30.2, U7.12
unnamed: J31.1, J31.2, U7.13
unnamed: J32.1, J32.2, J32.3, U4.8
unnamed: J33.1, J33.2, J33.3, U4.11
unnamed: J34.1, J34.2, J34.3, U5.3
unnamed: J35.1, J35.2, J35.3, U5.6
unnamed: J36.1, J36.2, J36.3, U5.8
unnamed: J37.1, J37.2, J37.3, U5.11
unnamed: J38.1, J38.2, J38.3, U6.3
unnamed: J39.1, J39.2, J39.3, U6.6
unnamed: J40.1, J40.2, J40.3, U6.8
unnamed: J41.1, J41.2, J41.3, U6.11
unnamed: J42.1, J42.2, J42.3, U7.3
unnamed: J43.1, J43.2, J43.3, U7.6
unnamed: J44.1, J44.2, J44.3, U7.8
unnamed: J45.1, J45.2, J45.3, U7.11
unnamed: J46.1, J46.2, J46.3, U9.2
unnamed: J47.1, J47.2, J47.3, U9.3
unnamed: J48.1, J48.2, J48.3, U9.5
unnamed: J49.1, J49.2, J49.3, U9.6
unnamed: J50.1, J50.2, J50.3, U9.8
unnamed: J51.1, J51.2, J51.3, U9.9
unnamed: J52.1, J52.2, J52.3, U9.11
unnamed: J53.1, J53.2, J53.3, U9.12
unnamed: J54.1, J54.2, U8.1
unnamed: J55.1, J55.2, U8.2
unnamed: J56.1, J56.2, U8.4
unnamed: J57.1, J57.2, U8.5
unnamed: J58.1, J58.2, U8.9
unnamed: J59.1, J59.2, U8.10
unnamed: J60.1, J60.2, U8.12
unnamed: J61.1, J61.2, U8.13
unnamed: J62.1, J62.2, U3.1
unnamed: J63.1, J63.2, U3.2
unnamed: J64.1, J64.2, U3.5
unnamed: J65.1, J65.2, U3.6
unnamed: J66.1, J66.2, U3.8
unnamed: J67.1, J67.2, U3.9
unnamed: J68.1, J68.2, U3.12
unnamed: J69.1, J69.2, U3.13
unnamed: J70.1, J70.2, J70.3, U9.1
unnamed: J71.1, J71.2, J71.3, U9.4
unnamed: J72.1, J72.2, J72.3, U9.10
unnamed: J73.1, J73.2, J73.3, U9.13
unnamed: J74.1, J74.2, J74.3, U8.3
unnamed: J75.1, J75.2, J75.3, U8.6
unnamed: J76.1, J76.2, J76.3, U8.8
unnamed: J77.1, J77.2, J77.3, U8.11
unnamed: J78.1, J78.2, J78.3, U3.3
unnamed: J79.1, J79.2, J79.3, U3.4
unnamed: J80.1, J80.2, J80.3, U3.10
unnamed: J81.1, J81.2, J81.3, U3.11
unnamed: J82.1, U1.1
unnamed: J82.2, U1.3
unnamed: J82.3, U1.5
unnamed: J82.4, U1.9
unnamed: J82.5, U1.11
unnamed: J82.6, U1.13
unnamed: J83.1, U2.1
unnamed: J83.2, U2.3
unnamed: J83.3, U2.5
unnamed: J83.4, U2.9
unnamed: J83.5, U2.11
unnamed: J83.6, U2.13
unnamed: J84.1, U1.2
unnamed: J84.2, U1.4
unnamed: J84.3, U1.6
unnamed: J84.4, U1.8
unnamed: J84.5, U1.10
unnamed: J84.6, U1.12
unnamed: J85.1, U2.2
unnamed: J85.2, U2.4
unnamed: J85.3, U2.6
unnamed: J85.4, U2.8
unnamed: J85.5, U2.10
unnamed: J85.6, U2.12
unnamed: J86.1, U10.1 (OEa)
unnamed: J86.2, U10.2 (I0a)
unnamed: J86.3, U10.4 (I1a)
unnamed: J86.4, U10.6 (I2a)
unnamed: J86.5, U10.8 (I3a)
unnamed: J86.6, U10.11 (I0b)
unnamed: J86.7, U10.13 (I1b)
unnamed: J86.8, U10.15 (I2b)
unnamed: J86.9, U10.17 (I3b)
unnamed: J86.10, U10.19 (OEb)
unnamed: J88.1, U11.2 (A0)
unnamed: J88.2, U11.3 (A1)
unnamed: J88.3, U11.4 (A2)
unnamed: J88.4, U11.5 (A3)
unnamed: J88.5, U11.6 (A4)
unnamed: J88.6, U11.7 (A5)
unnamed: J88.7, U11.8 (A6)
unnamed: J88.8, U11.9 (A7)
unnamed: J89.1, U11.1 (A->B)
unnamed: J89.2, U11.19 (CE)
unnamed: J90.1, U10.18 (O0a)
unnamed: J90.2, U10.16 (O1a)
unnamed: J90.3, U10.14 (O2a)
unnamed: J90.4, U10.12 (O3a)
unnamed: J90.5, U10.9 (O0b)
unnamed: J90.6, U10.7 (O1b)
unnamed: J90.7, U10.5 (O2b)
unnamed: J90.8, U10.3 (O3b)
unnamed: J91.1, U11.18 (B0)
unnamed: J91.2, U11.17 (B1)
unnamed: J91.3, U11.16 (B2)
unnamed: J91.4, U11.15 (B3)
unnamed: J91.5, U11.14 (B4)
unnamed: J91.6, U11.13 (B5)
unnamed: J91.7, U11.12 (B6)
unnamed: J91.8, U11.11 (B7)
unnamed: J95.3, J96.5 (GND), J96.6 (Shield)
unnamed: J97.1, U14.4 (D0)
unnamed: J97.2, U14.5 (D1)
unnamed: J97.3, U14.12 (D2)
unnamed: J97.4, U14.13 (D3)
unnamed: J98.1, U13.3 (D0)
unnamed: J98.2, U13.4 (D1)
unnamed: J98.3, U13.6 (D2)
unnamed: J98.4, U13.11 (D3)
unnamed: J98.5, U13.13 (D4)
unnamed: J98.6, U13.14 (D5)
unnamed: J99.1, U13.9 (Cp)
unnamed: J99.2, U13.1 (~Mr)
unnamed: J100.1, U14.9 (Cp)
unnamed: J100.2, U14.1 (~Mr)
unnamed: J101.1, U15.3 (D0)
unnamed: J101.2, U15.4 (D1)
unnamed: J101.3, U15.7 (D2)
unnamed: J101.4, U15.8 (D3)
unnamed: J101.5, U15.13 (D4)
unnamed: J101.6, U15.14 (D5)
unnamed: J101.7, U15.17 (D6)
unnamed: J101.8, U15.18 (D7)
unnamed: J102.1, U15.11 (LE)
unnamed: J102.2, U15.1 (OE)
unnamed: J103.1, U13.2 (Q0)
unnamed: J103.2, U13.5 (Q1)
unnamed: J103.3, U13.7 (Q2)
unnamed: J103.4, U13.10 (Q3)
unnamed: J103.5, U13.12 (Q4)
unnamed: J103.6, U13.15 (Q5)
unnamed: J104.1, U14.2 (Q0)
unnamed: J104.2, U14.3 (~Q0)
unnamed: J104.3, U14.7 (Q1)
unnamed: J104.4, U14.6 (~Q1)
unnamed: J104.5, U14.10 (Q2)
unnamed: J104.6, U14.11 (~Q2)
unnamed: J104.7, U14.15 (Q3)
unnamed: J104.8, U14.14 (~Q3)
unnamed: J105.1, U15.2 (O0)
unnamed: J105.2, U15.5 (O1)
unnamed: J105.3, U15.6 (O2)
unnamed: J105.4, U15.9 (O3)
unnamed: J105.5, U15.12 (O4)
unnamed: J105.6, U15.15 (O5)
unnamed: J105.7, U15.16 (O6)
unnamed: J105.8, U15.19 (O7)
unnamed: J106.1, U17.8 (J)
unnamed: J106.2, U17.9 (C)
unnamed: J106.3, U17.11 (K)
unnamed: J107.1, U16.3 (J)
unnamed: J107.2, U16.1 (C)
unnamed: J107.3, U16.2 (K)
unnamed: J108.1, U16.11 (J)
unnamed: J108.2, U16.13 (C)
unnamed: J108.3, U16.12 (K)
unnamed: J109.1, U17.5 (Q)
unnamed: J109.2, U17.6 (~Q)
unnamed: J110.1, J110.2, U17.10 (~R)
unnamed: J111.1, U16.5 (Q)
unnamed: J111.2, U16.6 (~Q)
unnamed: J112.1, U16.9 (Q)
unnamed: J112.2, U16.7 (~Q)
unnamed: J113.1, U16.4 (~S)
unnamed: J113.2, U16.15 (~R)
unnamed: J114.1, U16.10 (~S)
unnamed: J114.2, U16.14 (~R)
unnamed: J115.1, U18.3 (D0)
unnamed: J115.2, U18.4 (D1)
unnamed: J115.3, U18.5 (D2)
unnamed: J115.4, U18.6 (D3)
unnamed: J116.1, U18.9 (~PE)
unnamed: J116.2, U18.7 (CEP)
unnamed: J116.3, U18.10 (CET)
unnamed: J116.4, U18.2 (CP)
unnamed: J116.5, U18.1 (~MR)
unnamed: J117.1, U19.3 (D0)
unnamed: J117.2, U19.4 (D1)
unnamed: J117.3, U19.5 (D2)
unnamed: J117.4, U19.6 (D3)
unnamed: J118.1, U19.9 (~PE)
unnamed: J118.2, U19.7 (CEP)
unnamed: J118.3, U19.10 (CET)
unnamed: J118.4, U19.2 (CP)
unnamed: J118.5, U19.1 (~MR)
unnamed: J119.1, U18.14 (Q0)
unnamed: J119.2, U18.13 (Q1)
unnamed: J119.3, U18.12 (Q2)
unnamed: J119.4, U18.11 (Q3)
unnamed: J119.5, U18.15 (TC)
unnamed: J120.1, U19.14 (Q0)
unnamed: J120.2, U19.13 (Q1)
unnamed: J120.3, U19.12 (Q2)
unnamed: J120.4, U19.11 (Q3)
unnamed: J120.5, U19.15 (TC)
unnamed: J121.1, U20.2 (Dsr)
unnamed: J121.2, U20.3 (P0)
unnamed: J121.3, U20.4 (P1)
unnamed: J121.4, U20.5 (P2)
unnamed: J121.5, U20.6 (P3)
unnamed: J121.6, U20.7 (Dsl)
unnamed: J122.1, U20.9 (S0)
unnamed: J122.2, U20.10 (S1)
unnamed: J123.1, U20.11 (Cp)
unnamed: J123.2, U20.1 (Mr)
unnamed: J124.1, U21.2 (Dsr)
unnamed: J124.2, U21.3 (P0)
unnamed: J124.3, U21.4 (P1)
unnamed: J124.4, U21.5 (P2)
unnamed: J124.5, U21.6 (P3)
unnamed: J124.6, U21.7 (Dsl)
unnamed: J125.1, U21.9 (S0)
unnamed: J125.2, U21.10 (S1)
unnamed: J126.1, U21.11 (Cp)
unnamed: J126.2, U21.1 (Mr)
unnamed: J127.1, U20.15 (Q0)
unnamed: J127.2, U20.14 (Q1)
unnamed: J127.3, U20.13 (Q2)
unnamed: J127.4, U20.12 (Q3)
unnamed: J128.1, U21.15 (Q0)
unnamed: J128.2, U21.14 (Q1)
unnamed: J128.3, U21.13 (Q2)
unnamed: J128.4, U21.12 (Q3)
unnamed: J129.1, U22.5 (A1)
unnamed: J129.2, U22.3 (A2)
unnamed: J129.3, U22.14 (A3)
unnamed: J129.4, U22.12 (A4)
unnamed: J130.1, U22.6 (B1)
unnamed: J130.2, U22.2 (B2)
unnamed: J130.3, U22.15 (B3)
unnamed: J130.4, U22.11 (B4)
unnamed: J131.1, U23.9 (B0)
unnamed: J131.2, U23.11 (B1)
unnamed: J131.3, U23.14 (B2)
unnamed: J131.4, U23.1 (B3)
unnamed: J132.1, U23.10 (A0)
unnamed: J132.2, U23.12 (A1)
unnamed: J132.3, U23.13 (A2)
unnamed: J132.4, U23.15 (A3)
unnamed: J134.1, U22.4 (S1)
unnamed: J134.2, U22.1 (S2)
unnamed: J134.3, U22.13 (S3)
unnamed: J134.4, U22.10 (S4)
unnamed: J134.5, U22.9 (C4)
unnamed: J135.1, U23.4 (Ia>b)
unnamed: J135.2, U23.2 (Ia<b)
unnamed: J135.3, U23.3 (Ia=b)
unnamed: J136.1, U23.5 (Oa>b)
unnamed: J136.2, U23.7 (Oa<b)
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
